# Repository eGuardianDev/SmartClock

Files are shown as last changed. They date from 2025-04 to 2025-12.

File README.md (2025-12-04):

# SmartClock
A small "smart" alarm clock for IoT course.

### Idea
A small clock with alarm and basic functions. Integrationg with WiFi via ESP32 for data sharing, maybe smart home automation. Different sensors for tracking enviroment data and sleep patterns.

### Restart of project
 - [ ] Change from arduino ide to platformio
 - [ ] Refactor RTC functions
 - [ ] Refactor display functions
 - [ ] Refactor pages system
 - [ ] Refactor bme280 sensors
 - [ ] Add sleep mode
 - [ ] Fix button design
 - [ ] Add lights for the display

## Documentation

### Tools
 - [Bit map to code](https://www.teachmemicro.com/lcd-bitmap-converter-online/)

### Parts
- Display: probably E-Ink or 7-segment.
- Sensors: Microphone for noise, temperature, humidity, light.
- Actuators control: attach lights and motor to make waking up easier.
- Main controller: ESP32

### Plans and ideas
- [X] Theoretical idea
- [X] Finding & ordering parts
  - [X] Finding compatable parts
  - [X] Making an order 
- [X] Testing parts and finding libraries
  - [X] Display 
    - E-Ink no touch 89x38cm - 296x128res [2.9" inch SPI](https://erelement.com/shop/e-ink-2-9-grey/)
  - [X] Sensors
    - ~~Microphone [Sound sensor wc](https://erelement.com/shop/sound-sensor-module/)~~
    - Enviroment [bme280](https://erelement.com/shop/bme280-ws/)
    - ~~Hand movement [qtr-md-08a](https://erelement.com/shop/qtr-md-08a/) [pir](https://erelement.com/shop/pir-sensor/)~~
    - light [photoresistor](https://elimex.bg/product/70488-fotorezistor-pgm5516-ldr5516)
    - ~~SD Card [reader](https://elimex.bg/product/75637-kit-k2162-micro-sd-kartochetets-za-uno)~~
  - [ ] ~~Actuators~~
  - [X] WiFi control 
- [X] Simple prototype
  - [X] WiFi server / API 
  - [X] Sensor and calibration
  - [ ] ~~Actuators connection~~
- [ ] Code
  - [X] Initialize everything
  - [X] Wifi connection
  - [X] Clock logic
  - [X] API logic 
    - [X] Weather 
    - [ ] Time sync 
    - [ ] Todo?
  - [ ] sleep tracking
  - [ ] calendar
  - [ ] Low-power/sleep mode 
- [X] Final design
  - [X] Container
  - [X] Compression of electronics
- [ ] Presentation material
  - [ ] Documentation 
    - [X] CAD design
    - [X] Schematics
    - [ ] Software
  - [X] Presentation
  - [X] Video?
  
### Current progress
 - [X] fix main page
 - [X] fix weather page
 - [ ] enter sleep mode
 - [X] add alarm
 - [X] test wifi provisioner
 - [ ] add time sync
 - [ ] hand move test
 - [ ] docs
 - [X] presentation

### problems met
 - bitmap size containment
 - system event configuration
 - hardware and electronics problem
 - usb charging
 - compilation time
 - interupts not fixed
 - maybe e-ink wasn't the best idea

### Settings and ideas
 - There should be different wake up patterns for the alarm. For example - ring 1 second, wait 3-5 seconds, repeat.
 - Extending the suspend button away, maybe using second ESP with ESP now protocol in deep sleep or unpowered.
 - sync alarm with phone
 - Weather forecast

### Diagram
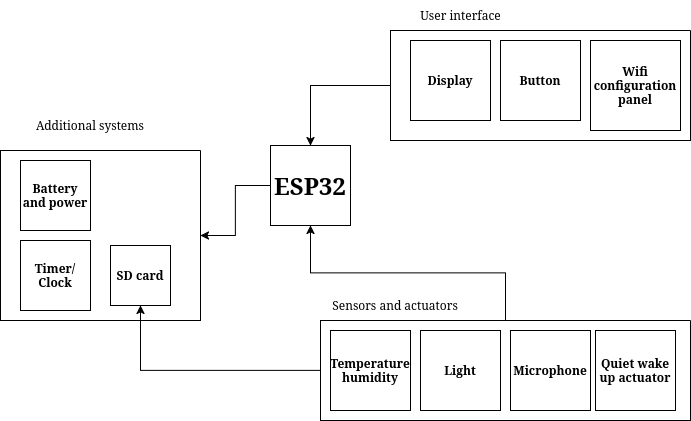
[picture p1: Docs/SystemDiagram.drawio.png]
Diagram


### Main body CAD design
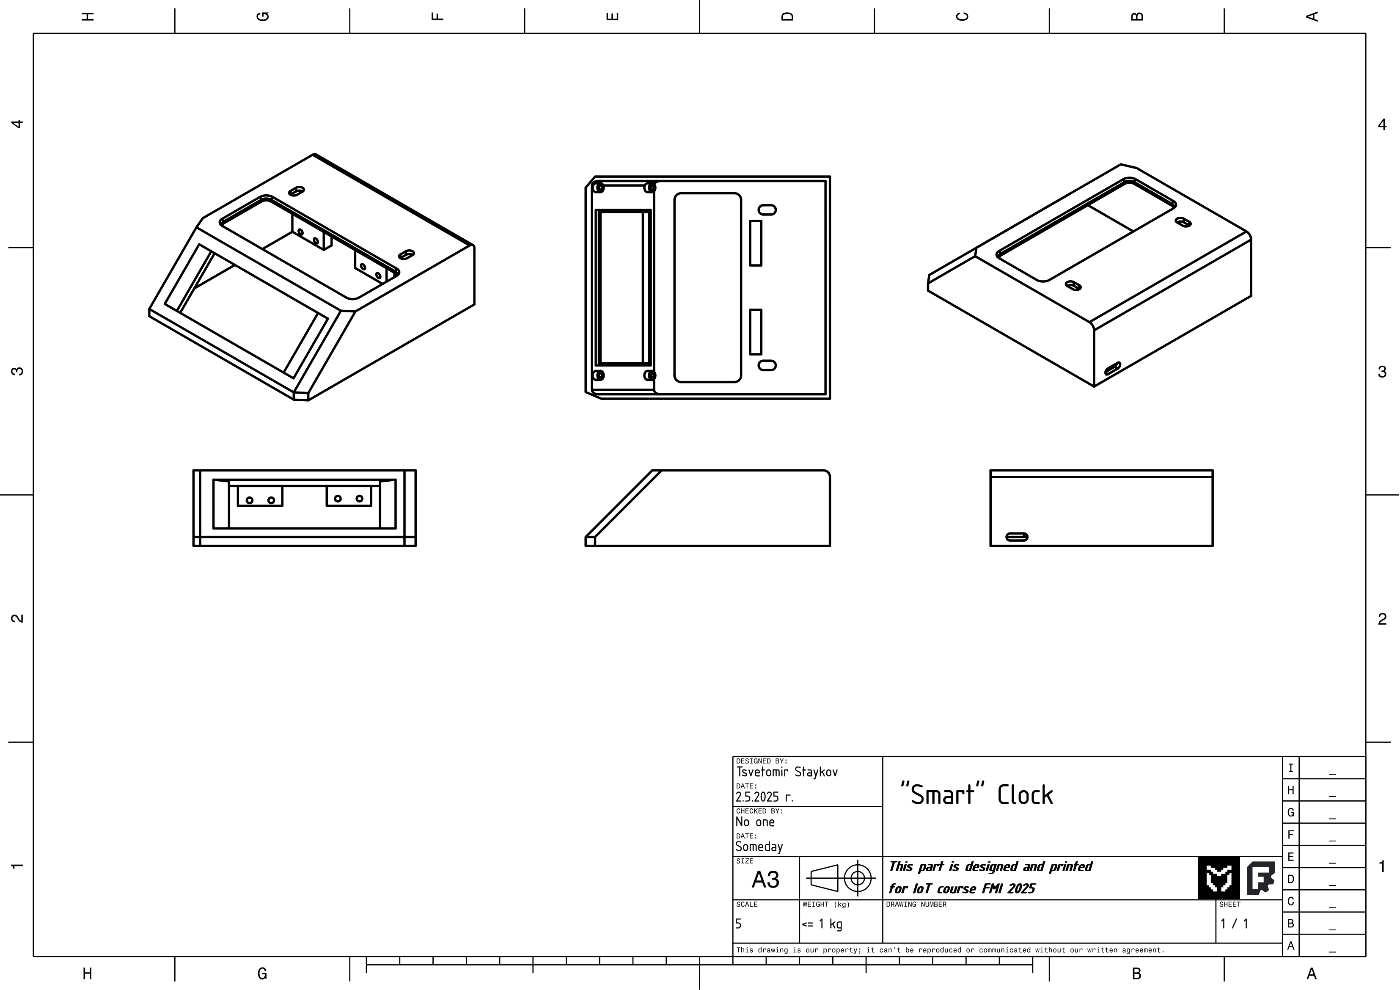
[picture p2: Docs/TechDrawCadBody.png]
TechDrawCadBody


### Electronics schematics
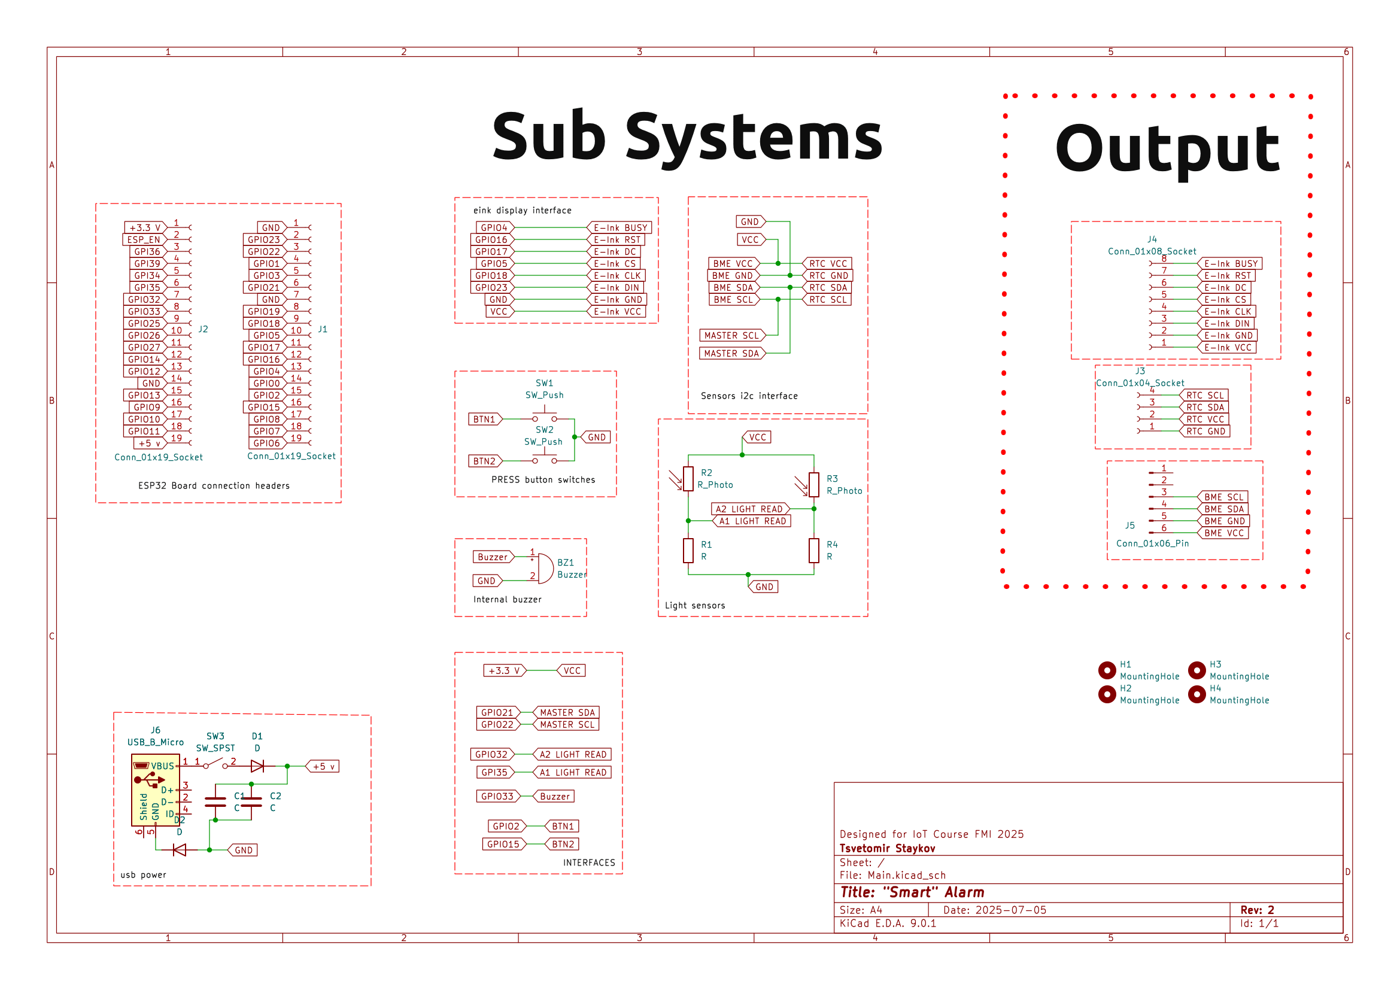
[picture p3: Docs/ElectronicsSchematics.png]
schematiElectronicsSchematicscs


### 3D PCB Design
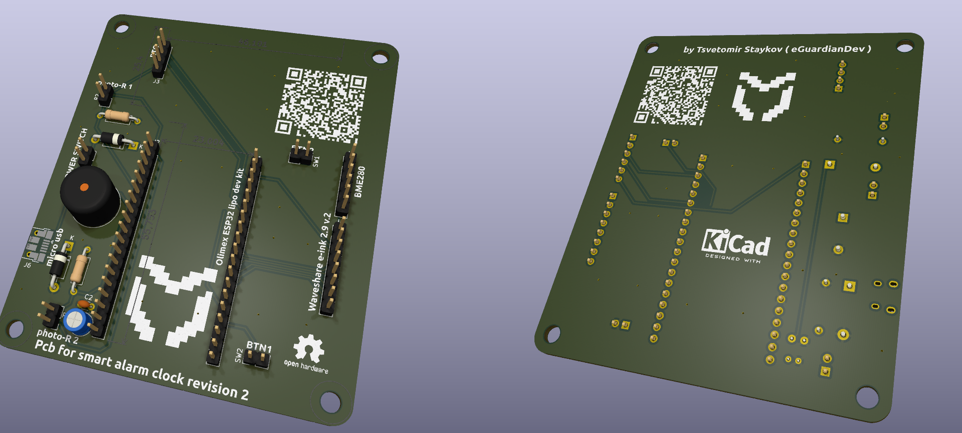
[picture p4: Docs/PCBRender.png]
render


### 3D render of all objects
render

---

Created for IoT Course FMI 2025.

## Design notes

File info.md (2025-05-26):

problems :
 - bitmap size too big for esp32 flash storage
 fix: download bitmap from internet
 
 - things won't fit in the box
 fix: change the scale of the project
 
 - time is limited
 fix: change the scale of the project
 
 - usb-c port doesn't allighn with output
 fix: permament cable. it is open source, you can open it and change it when it breaks
 
 - button design is bad and they float in the air, cause possible breakage 
 fix: have so many cables and sensors inside that they hold the buttons

possible features:
 - hand gesture - move hand over box to activate modes, change settings, display images or information
 - new form factor
 - flip alarm simulation

 65x65

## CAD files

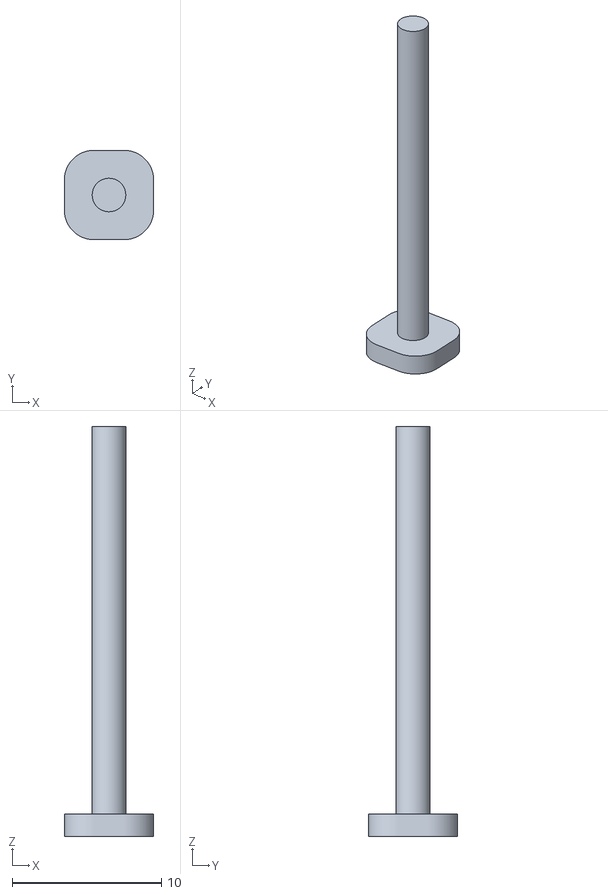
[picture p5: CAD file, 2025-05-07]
CAD/Print1/pin-switches.stl
6.00 x 6.00 x 27.5

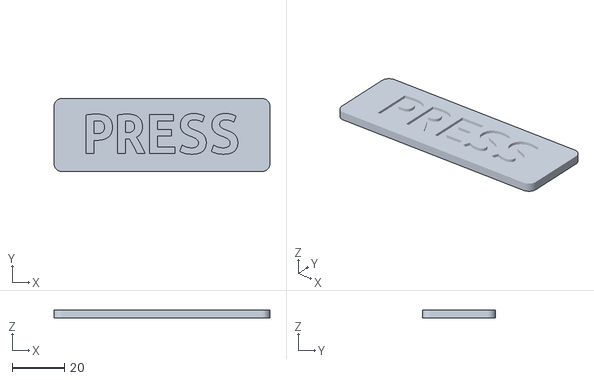
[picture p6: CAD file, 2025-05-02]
CAD/Prototypes/PressButton-Body.stl
83.0 x 28.0 x 3.00

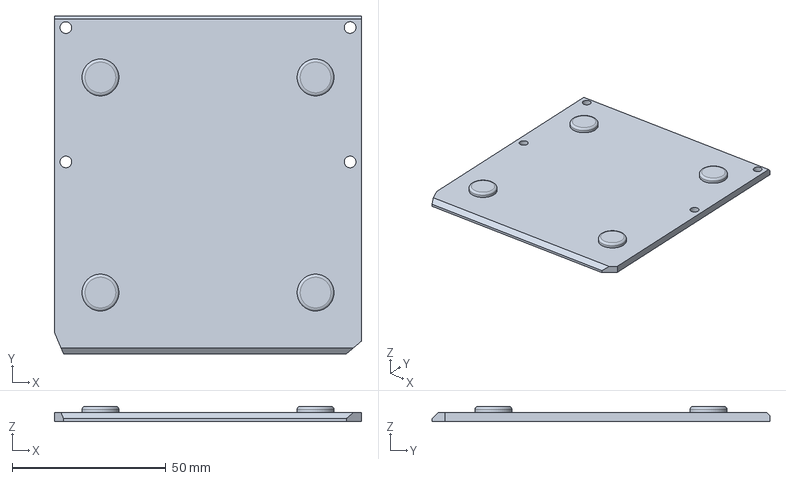
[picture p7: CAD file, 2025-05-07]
CAD/UnderLid.FCStd
100.0 x 110.0 x 5.00 mm

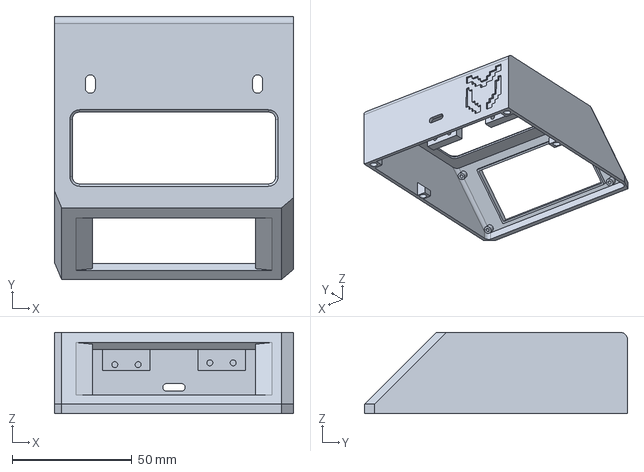
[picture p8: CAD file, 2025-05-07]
CAD/Body.FCStd
100.0 x 110.0 x 34.0 mm

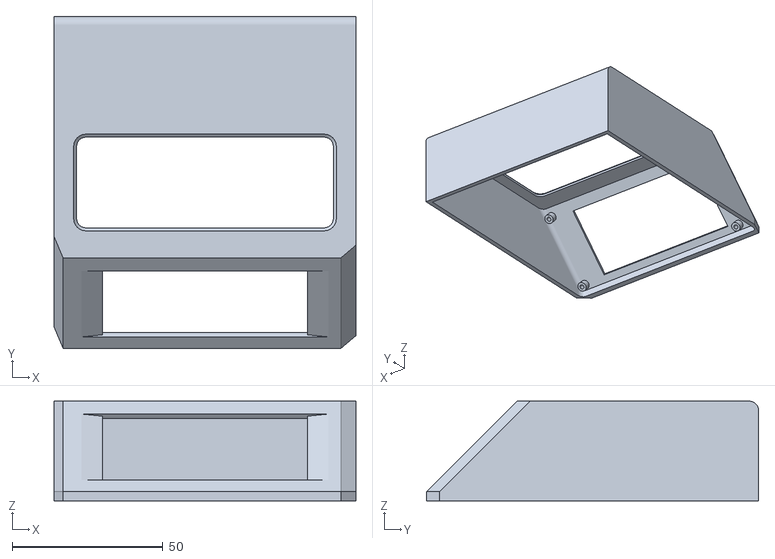
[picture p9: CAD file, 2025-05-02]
CAD/Prototypes/Body-Body2.stl
100.0 x 110.0 x 33.0

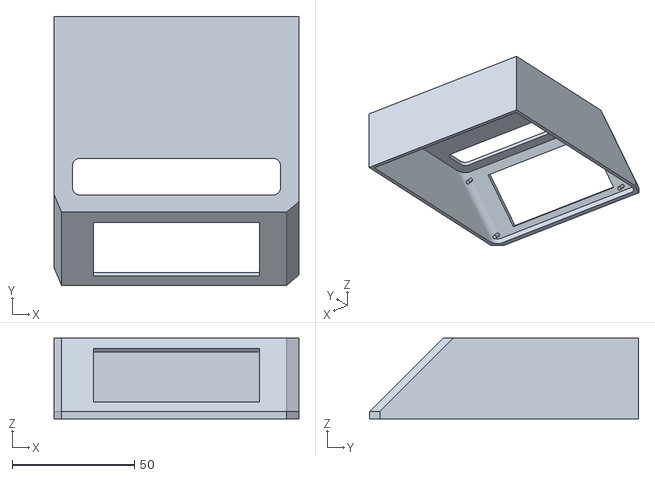
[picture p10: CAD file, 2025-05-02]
CAD/Prototypes/Body-Body.stl
100.0 x 110.0 x 33.0

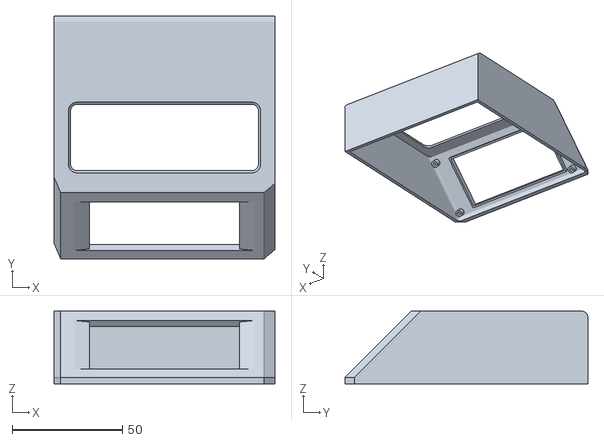
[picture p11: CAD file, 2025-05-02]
CAD/Prototypes/Body-Body3.stl
100.0 x 110.0 x 33.0

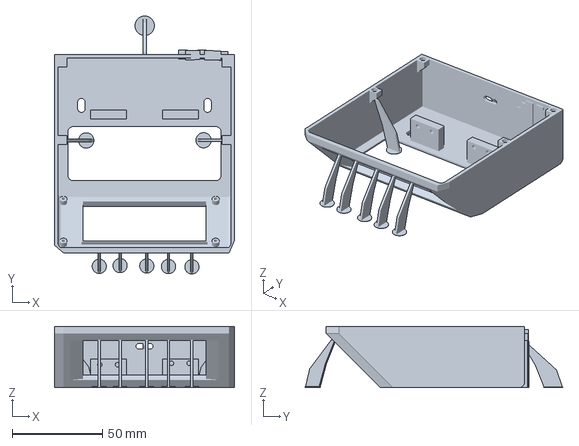
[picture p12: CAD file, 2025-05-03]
CAD/Print1/SmartClockBody.3mf
100.0 x 143.1 x 34.0 mm

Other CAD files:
CAD/Print1/Body.stl
CAD/pin-switches.FCStd
CAD/Print1/PressButton.stl
CAD/PressButton.FCStd
CAD/Print1/UnderLid.stl
CAD/Prototypes/Body-Body4.stl

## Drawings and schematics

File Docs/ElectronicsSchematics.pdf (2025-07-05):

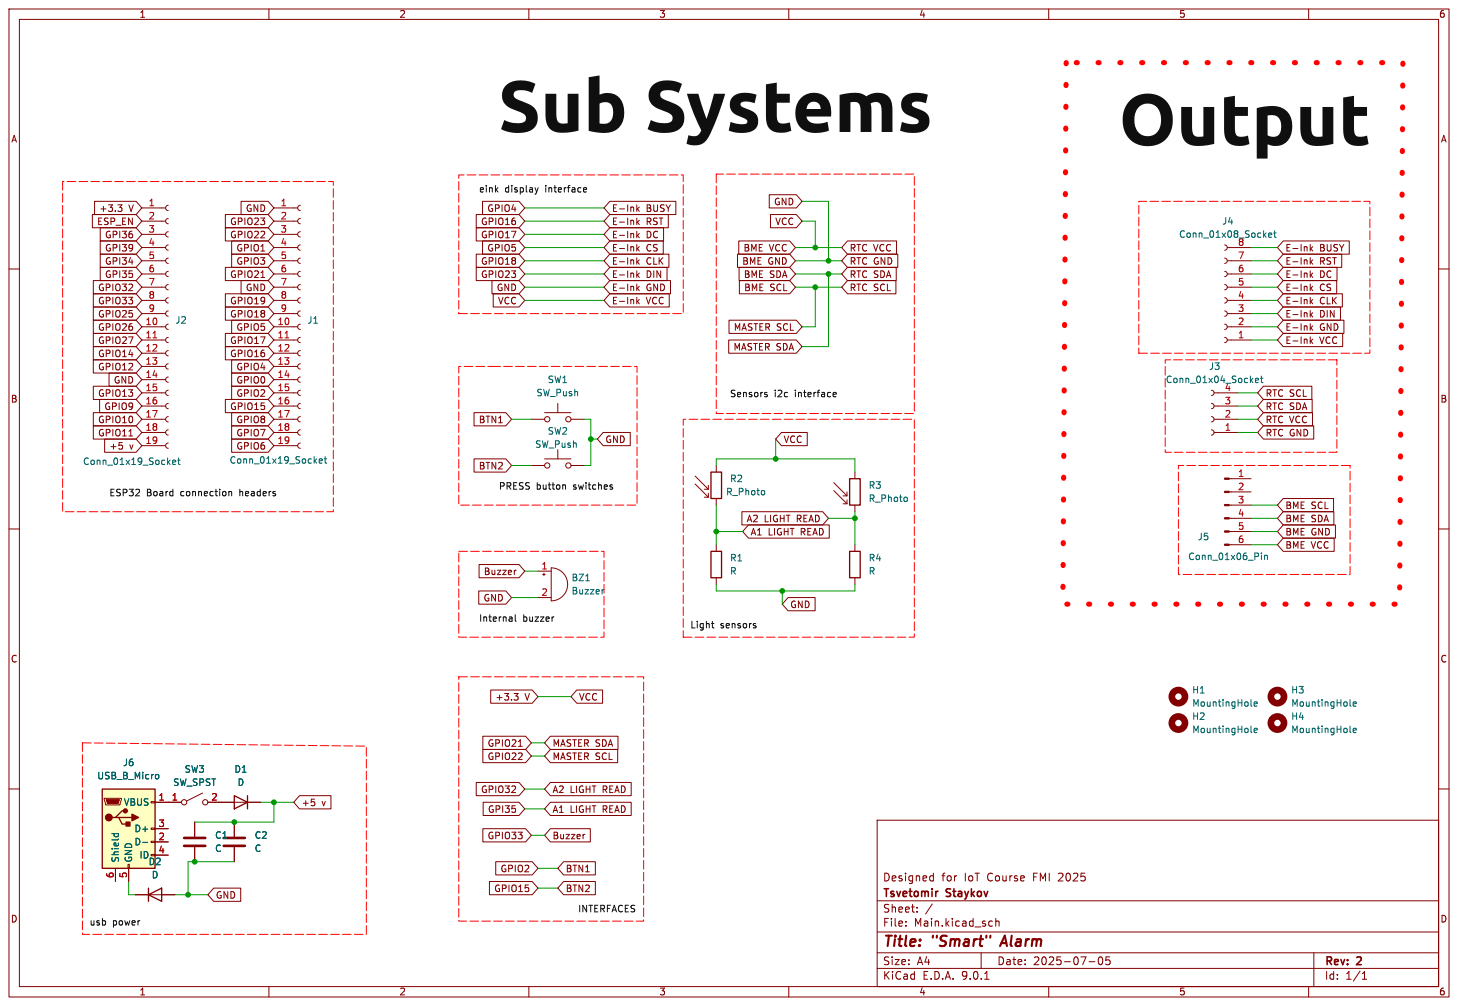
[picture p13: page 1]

PRESS button switches Sub Systems

BME SCL BME SDA GND
VCC

BME VCC
BME GND
RTC SDA MASTER SCL MASTER SDA

RTC VCC
RTC SCL RTC GND

File: Main.kicad_sch Sheet: / Tsvetomir Staykov

Id: 1/1 Title: "Smart" Alarm

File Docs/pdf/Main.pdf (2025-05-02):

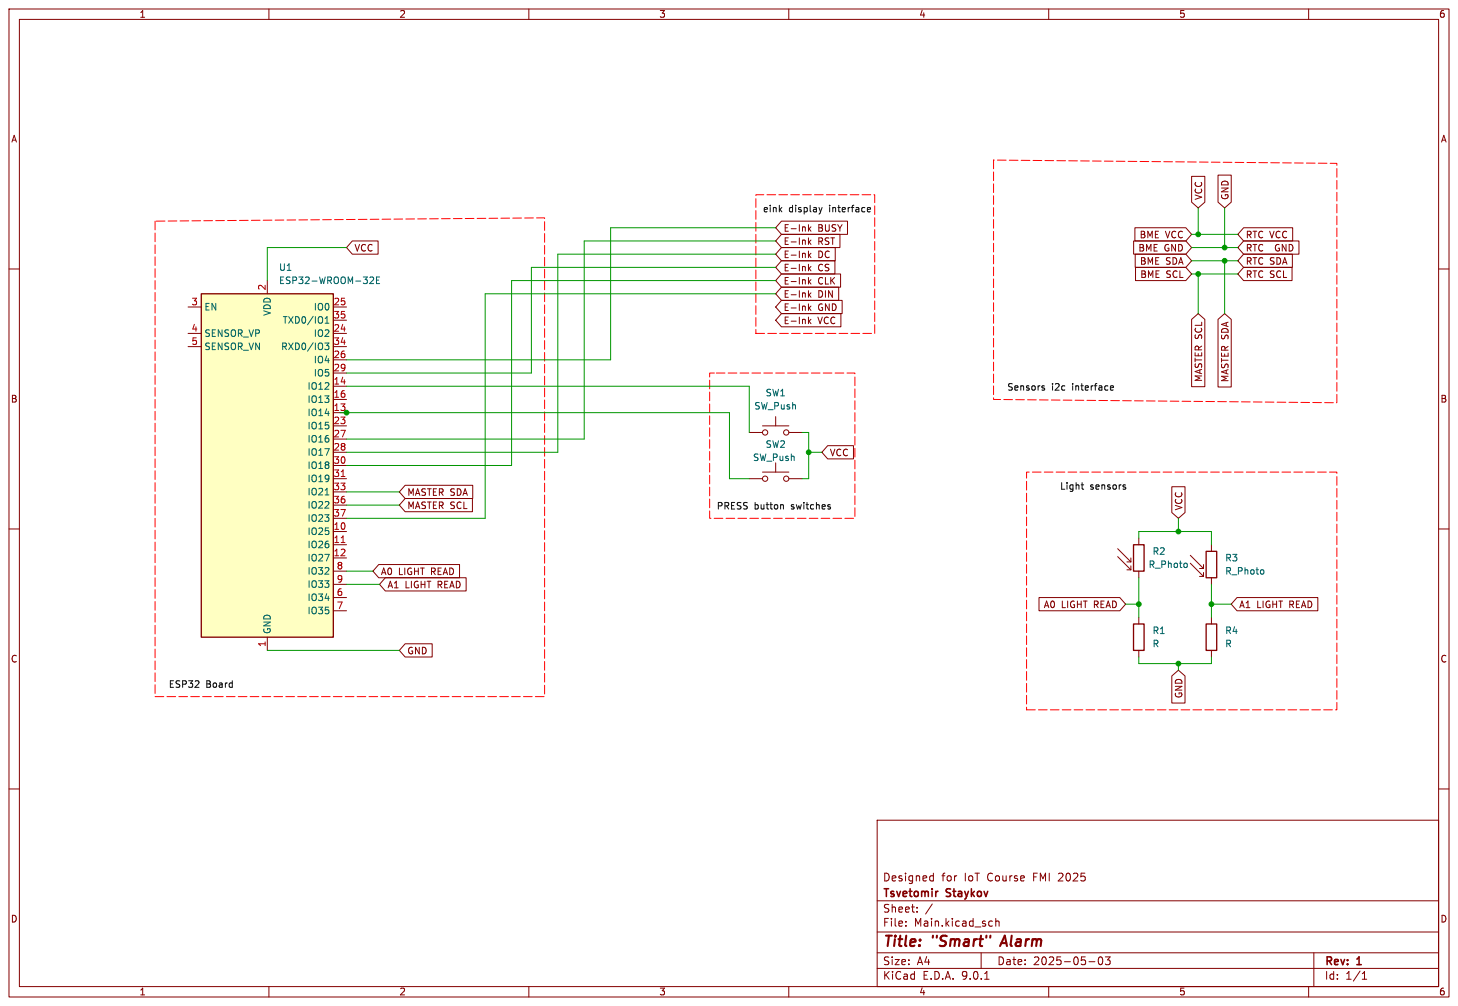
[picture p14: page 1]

File: Main.kicad_sch Sheet: / Tsvetomir Staykov

Id: 1/1 Title: "Smart" Alarm

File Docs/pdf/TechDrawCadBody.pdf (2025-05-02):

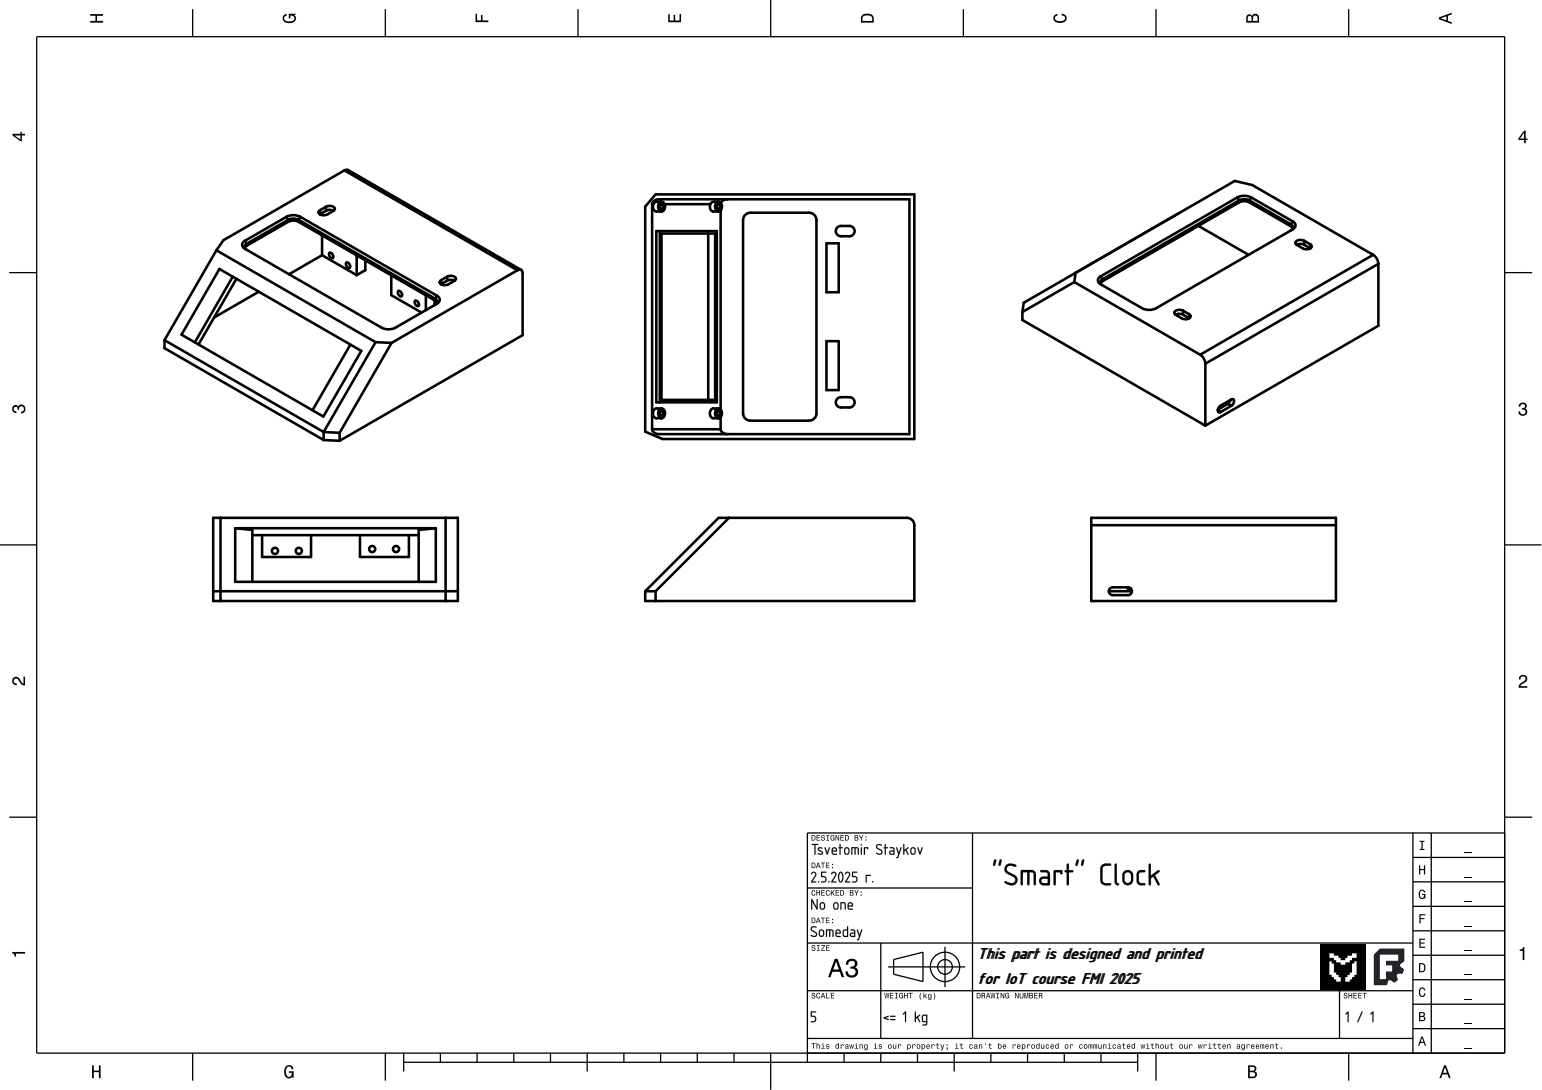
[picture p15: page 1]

This part is designed and printed
for IoT course FMI 2025

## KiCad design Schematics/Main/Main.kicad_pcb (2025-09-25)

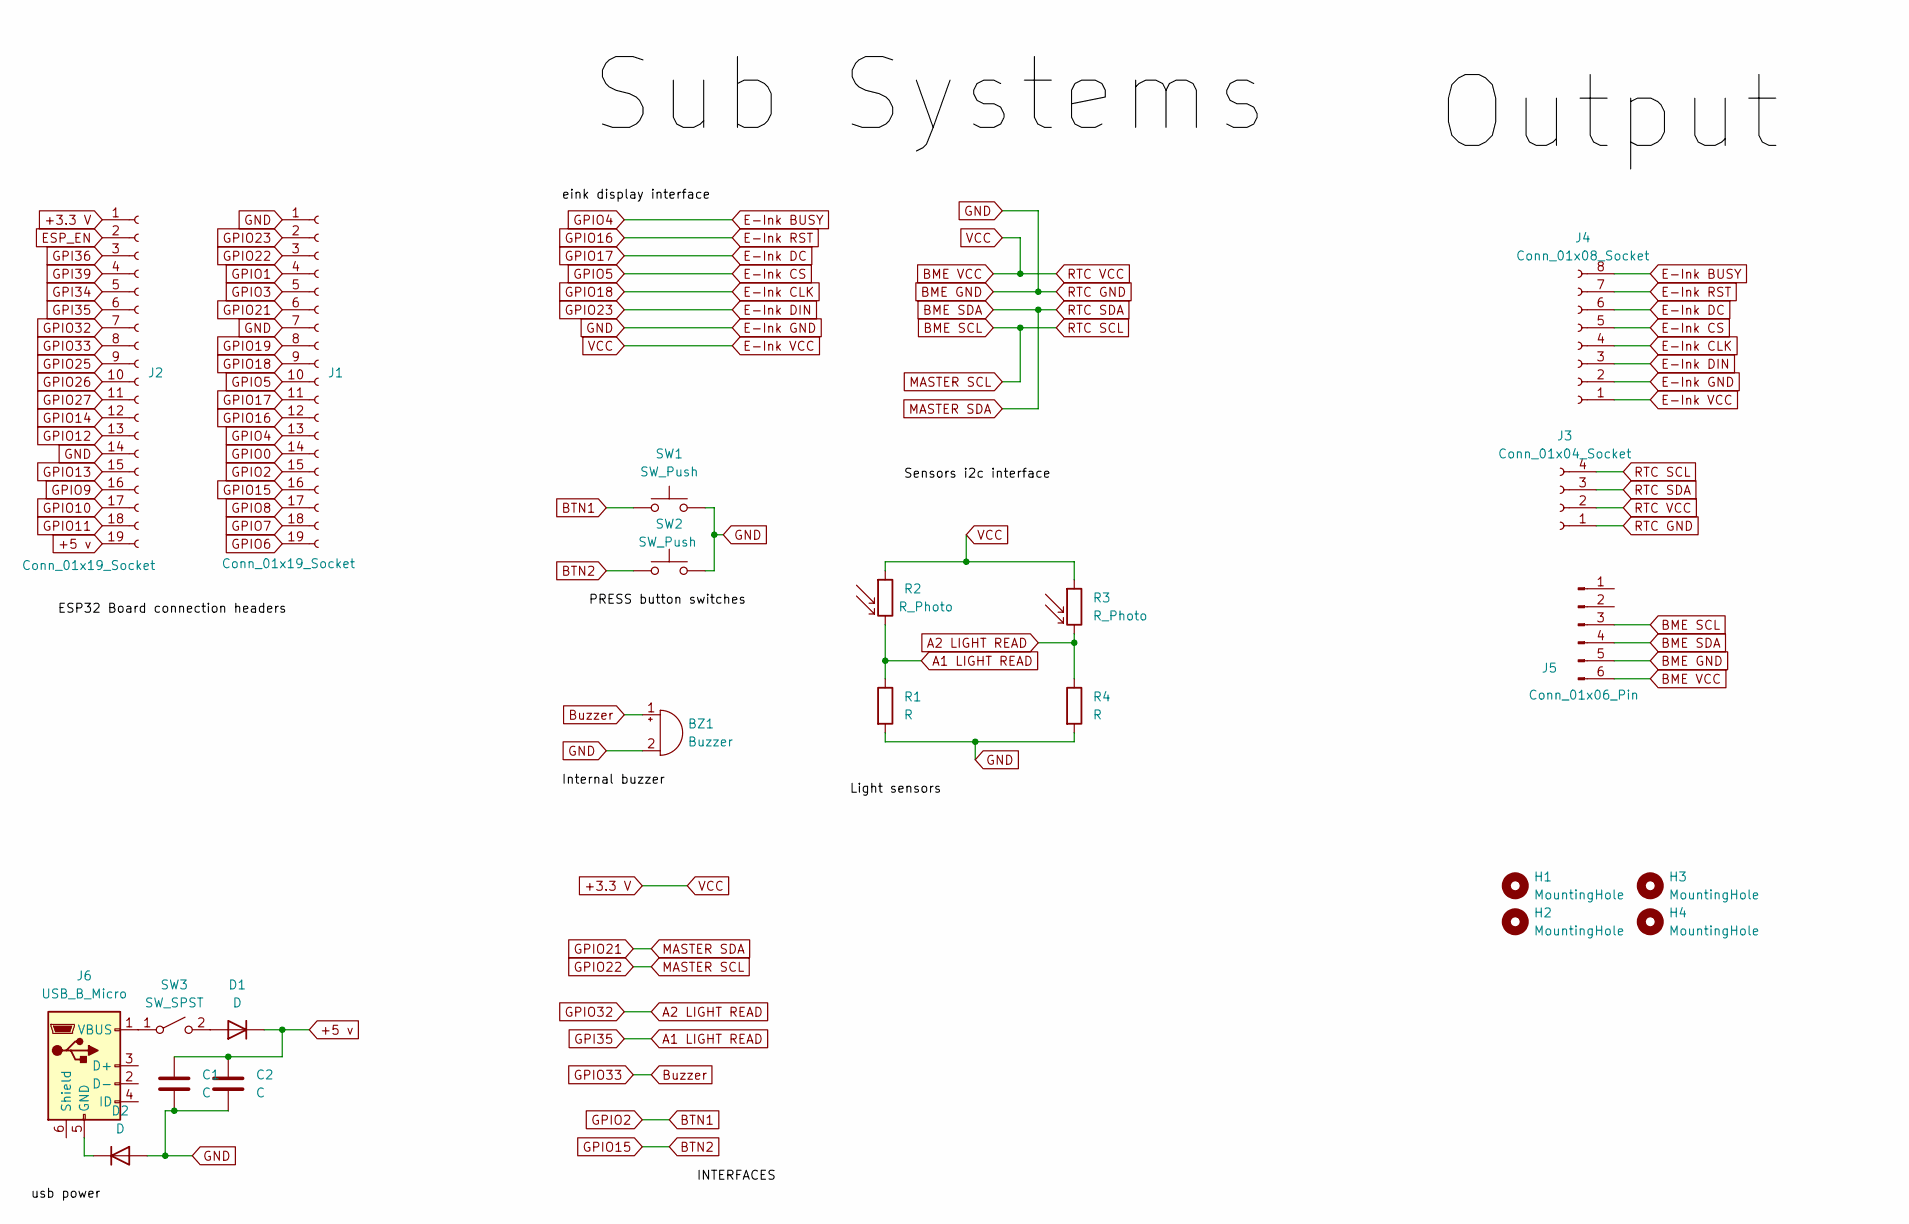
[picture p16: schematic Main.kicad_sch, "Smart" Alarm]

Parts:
BZ1: Buzzer; Buzzer_12x9.5RM7.6
C1: C; C_Radial_D5.0mm_H5.0mm_P2.00mm
C2: C; C_Disc_D3.0mm_W1.6mm_P2.50mm
D1, D2: D; D_DO-41_SOD81_P10.16mm_Horizontal
H1, H2, H3, H4: MountingHole; MountingHole_4mm
J1, J2: Conn_01x19_Socket; PinHeader_1x19_P2.54mm_Vertical
J3: Conn_01x04_Socket; PinHeader_1x04_P2.54mm_Vertical
J4: Conn_01x08_Socket; PinHeader_1x08_P2.54mm_Vertical
J5: Conn_01x06_Pin; PinHeader_1x06_P2.54mm_Vertical
J6: USB_B_Micro; USB_Micro-B_Amphenol_10103594-0001LF_Horizontal
R1, R4: R; R_Axial_DIN0207_L6.3mm_D2.5mm_P10.16mm_Horizontal
R2, R3: R_Photo; PinHeader_1x02_P2.54mm_Vertical
SW1, SW2: SW_Push; PinHeader_1x02_P2.54mm_Vertical
SW3: SW_SPST; PinHeader_1x02_P2.54mm_Vertical

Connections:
+3.3 V: J2.1, J3.2, J4.1, J5.6, R2.1, R3.1
+5 v: C1.1, C2.1, D1.1 (K), J2.19
A1 LIGHT READ: J2.6, R1.1, R2.2
A2 LIGHT READ: J2.7, R3.2, R4.1
BME GND: BZ1.2 (-), C1.2, C2.2, D2.2 (A), J1.1, J1.7, J2.14, J3.1, J4.2, J5.5, R1.2, R4.2, SW1.2, SW2.2
BME SCL: J1.3, J3.4, J5.3
BME SDA: J1.6, J3.3, J5.4
BTN1: J1.15, SW1.1
BTN2: J1.16, SW2.1
Buzzer: BZ1.1 (+), J2.8
E-Ink BUSY: J1.13, J4.8
E-Ink CLK: J1.9, J4.4
E-Ink CS: J1.10, J4.5
E-Ink DC: J1.11, J4.6
E-Ink DIN: J1.2, J4.3
E-Ink RST: J1.12, J4.7
ESP_EN: J2.2
GPI34: J2.5
GPI36: J2.3
GPI39: J2.4
GPIO0: J1.14
GPIO1: J1.4
GPIO3: J1.5
GPIO6: J1.19
GPIO7: J1.18
GPIO8: J1.17
GPIO9: J2.16
GPIO10: J2.17
GPIO11: J2.18
GPIO12: J2.13
GPIO13: J2.15
GPIO14: J2.12
GPIO19: J1.8
GPIO25: J2.9
GPIO26: J2.10
GPIO27: J2.11
unnamed: D1.2 (A), SW3.2 (B)
unnamed: D2.1 (K), J6.5 (GND)
unnamed: J6.1 (VBUS), SW3.1 (A)

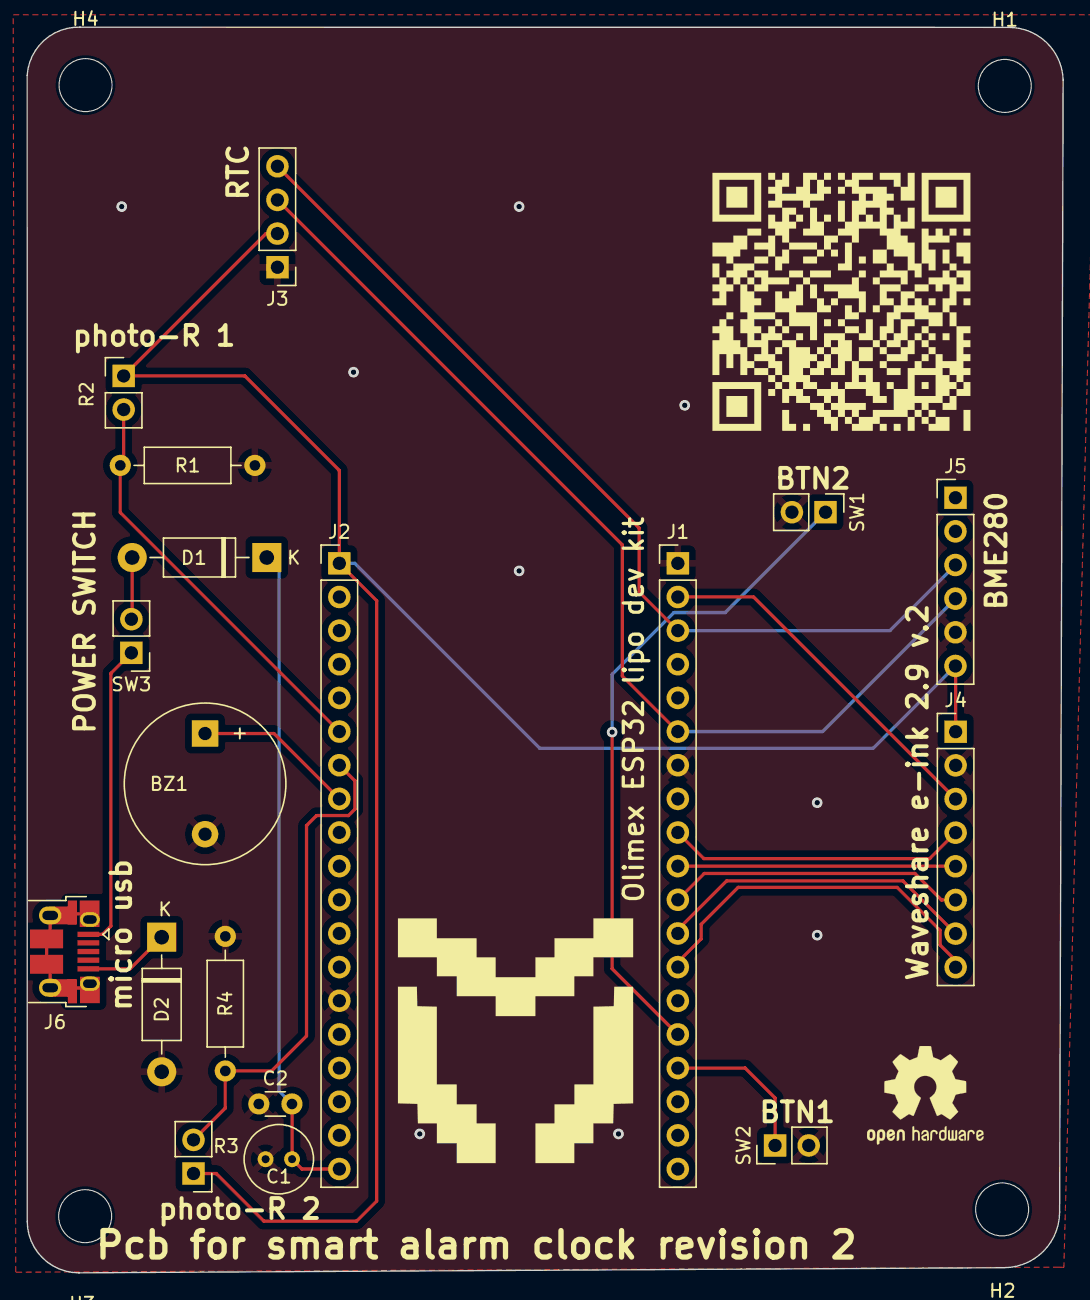
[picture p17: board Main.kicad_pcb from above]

Board: 2 copper layers, 78.2 x 94.0 mm, 22 parts (0 on the bottom side), 19 nets.

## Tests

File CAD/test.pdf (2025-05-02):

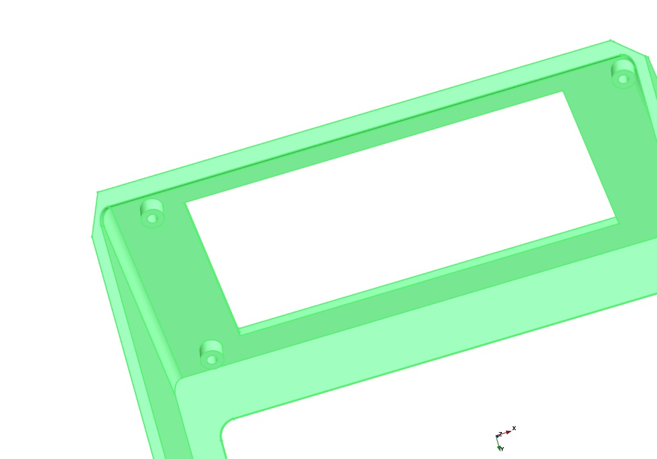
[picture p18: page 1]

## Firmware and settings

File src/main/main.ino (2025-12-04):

#define DebugOn


#include "pins.hpp"
#include "Logger.hpp"

Logger logger;

#include "Libraries.hpp"
#include "Display.hpp"
#include "EnviromentalSensors.hpp"
#include "RTCModule.hpp"
#include "SerialCommunication.hpp"
#include "DisplayPages.hpp"

#include "Wifi.hpp"
#include "Weather.hpp"
#include "Alarm.hpp"

#include "Logic.hpp"

#include "WebPage.hpp"


#ifdef DebugOn


void Debugged(){

  logger.log("Debug mode is on!");
  
  char temp[10];
  dtostrf(getTemp(), 5, 2, temp);
  logger.debug(String("Temp is ") + temp +  " °C"); 
 
  char hour[4];
  char minute[4];
  char second[4];
  dtostrf(getHour(), 2, 0, hour);
  dtostrf(getMinute(), 2, 0, minute);
  dtostrf(getSecond(), 2, 0, second);
  String currTime =  String("") + hour + ":" + minute;
  logger.debug(currTime);
  logger.debug(String("Current wifi state: ") + checkWifiConnection());
  
  logger.debug(WiFi.localIP().toString());

  logger.debug(String("Light level: ") + val_light1 + " | " + val_light2);

  logger.debug(String("Buttons pressed: ") + val_button1 + " | " + val_button2);

}
#endif

void setup() {

  // =======   setup software ready   ========
  logger.init();
  
  // ======= setup hardware & sensors ===============
  setupBuzzer();
  delay(10);
  testBuzzer();

  setupScreen();

  // displayBitmapTest();

  setupBME();
  setupRTC();

  setupButtons();
  
  // =====    wifi settings    =======

  if(setupWifi()){
    setupWebServer();
    setup_mDNS();
  }


  // =======      Apps    ============
  setupWeather();
  setupAlarm();

  E_State = IDLE;
}


void loop() {
  Logger logger;
  
  buttonCheck();
  SerialRun();

  readButton();
  readLight();

  DisplayPage(true);
  loopServer();
  checkAlarm();

  #ifdef DebugOn
    Debugged();  
  #endif
  delay(100);
}

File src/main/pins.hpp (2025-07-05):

  
// --- lights ---
#define pin_light1 35  //INPUT
#define pin_light2 32  //INPUT

// --- buttons ---
#define pin_button1 2  //INPUT_PULLUP
#define pin_button2 15 //INPUT_PULLUP 

#define pin_button1_gnd 33 //OUTPUT (always low)
#define pin_button2_gnd 32 //OUTPUT (always low)

// --- buzzer ---
#define pin_buzzer 33 // OUTPUT PWM

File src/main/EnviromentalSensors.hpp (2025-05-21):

#ifndef _EnviromentalSensors_hpp__
#define _EnviromentalSensors_hpp__

#define SEALEVELPRESSURE_HPA (1013.25)

// ============================
//  temp and humidity sensors
// ============================

Adafruit_BME280 bme; 
bool BME280SensorReady = false;
void setupBME() {
  Logger logger;
  logger.log("Starting BME280 sensor for humidity, temp, altitude");
  unsigned status;
  status = bme.begin();  
  if (!status) {
    logger.error("Could not find a valid BME280 sensor, check wiring, address, sensor ID!");
    BME280SensorReady = false;
    return;
  }
  BME280SensorReady = true;
}


float getTemp(){
  if(!BME280SensorReady){ return 0; }
  // °C
  return (float) bme.readTemperature();
}

float getPressure(){
  if(!BME280SensorReady){ return 0; }
  // hPa
  return (float) bme.readPressure() / 100.0F;
}

float getAltitude(){
  if(!BME280SensorReady){ return 0; }
  // m
  return (float) bme.readAltitude(SEALEVELPRESSURE_HPA);
}

float getHumidity(){
  if(!BME280SensorReady){ return 0; }
  // %
  return (float) bme.readHumidity();
}

// ============================
//       light sensors
// ============================

int val_light1 = 0;
int val_light2 = 0;

void setupLightSensors(){
  
}

void readLight(){
  val_light1 = analogRead(pin_light1);
  val_light2 = analogRead(pin_light2);
}


// ============================
//  button press
// ============================

bool val_button1, val_button2;
void setupButtons(){
  pinMode(pin_button1,INPUT_PULLUP);
  pinMode(pin_button2,INPUT_PULLUP);
  // pinMode(pin_button1_gnd,OUTPUT);
  // pinMode(pin_button2_gnd,OUTPUT);
  // digitalWrite(pin_button1_gnd,LOW);
  // digitalWrite(pin_button2_gnd,LOW);
  
}

void readButton(){
  val_button1 = !digitalRead(pin_button1);
  val_button2 = !digitalRead(pin_button2);
}


//================== buzzer ==================


void setupBuzzer(){
  Logger logger;
  logger.log("Setting buzzer");
  pinMode(pin_buzzer, OUTPUT);
}

void testBuzzer(){
  Logger logger;
  logger.log("Testing buzzer");
  for(int i =180; i<255;++i){
    analogWrite(pin_buzzer, i);
    delay(5);
  }
  analogWrite(pin_buzzer, 0);
}


#endif //_EnviromentalSensors_hpp__

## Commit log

2025-05-02 CAD 3d design, schematics, docs
    [Body-Body.stl, Body-Body2.stl, Body-Body3.stl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]
2025-05-03 first print
    [Body.FCStd, Body.stl, PressButton.stl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]
2025-05-04 final cad system
    [Body.FCStd, UnderLid.FCStd, pin-switches.FCStd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]
2025-05-13 seperate pins in code, added buzzer, fixed pinout
    [Main.kicad_sch]
2025-07-05 PCB design and revision 2
    [Main-B_Cu.gbr, Main-B_Mask.gbr, Main-B_Paste.gbr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]
2025-09-25 latest pcb
    [Main-B_Cu.gbr, Main-B_Mask.gbr, Main-B_Paste.gbr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]
